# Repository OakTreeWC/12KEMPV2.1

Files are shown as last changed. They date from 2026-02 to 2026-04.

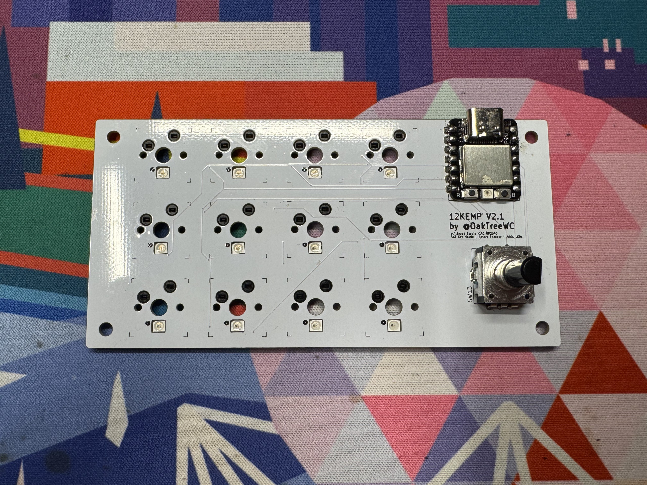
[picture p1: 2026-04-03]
Photos/IMG_2423.jpg

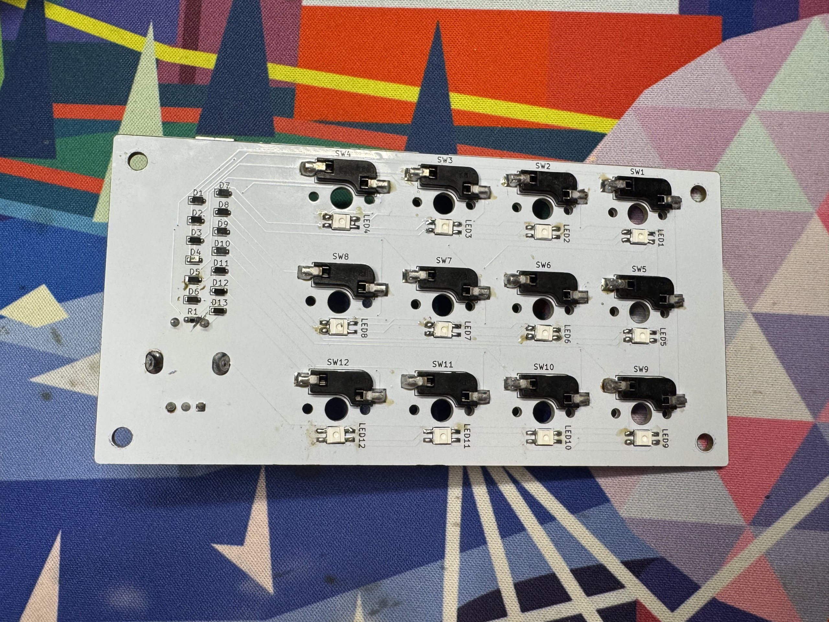
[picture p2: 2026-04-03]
Photos/IMG_2424.jpg

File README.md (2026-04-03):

# 12KEMP V2.1  (Complete)
12KEMP V2.1 is a 12 key 4 by 3 macropad, that features a Xiao SEEED Studio RP2040 with vial-qmk support, a clickable rotary encoder, a completely custom pcb with hot-swap support for 3/5-pin regular MX switches, as well as a complete case. All related files are in this repo, and you may create any form of case to mount the pcb onto, though it may take some time. Additionally, a bill of materials (BOM) is included. 

I made this project, 1. for school, and 2. for the [hackclub blueprint](https://blueprint.hackclub.com) event.

12kemp

## Installing the Firmware
In order to install the firmware on the SEEED Studio RP2040 (RP2350 is not supported in QMK yet), hold the boot button on the microcontroller while plugging it into your computer. Once plugged in, a USB Mass Storage Device should appear. Download and move the .uf2 [firmware file](https://github.com/OakTreeWC/12KEMPV2.1/raw/refs/heads/main/Production/firmware.uf2) to the device. After the firmware has been put on the flash, the microcontroller should restart automatically. The firmware has now been installed.

## Usage
In order to use this project, one can either download Vial from [get.vial.today](https://get.vial.today), or use their [web interface](https://vial.rocks/). When plugged in, the device should show up on the top in a little dropdown. (Web users may have to manually select the device when setting up) If necessary, select the device from the dropdown. Now you can manually change what each key on the macropad does, simply by clicking the key you want to change and selecting what you want it to do from the bottom. You can change what keys on the other layers do as well, by just clicking the numbers right under the dropdown on the left.






## Bill of Materials
|Item |Description |Qty.|Unit Price (USD)|Total Price  (USD)|URL |Running Total (USD + Tax)|
|---|---|----|---|---|---|---|
|XIAO RP2040 |ARM® Cortex®-M0+ MCU 32-Bit Embedded Evaluation Board |1 |$4.68 |$4.68 |https://www.digikey.com/en/products/detail/seeed-technology-co-ltd/102010428/14672129 |$5.16 |
|Rotary Encoder |Rotary Encoder Incremental 24 Quadrature (Incremental) Horizontal |1 |$1.72 |$1.72 |https://www.digikey.com/en/products/detail/bourns-inc/PEC12R-4020F-S0024/4699271 |$7.06 |
|Reverse Neopixels |Addressable Lighting - 10 LED Discrete Red, Green, Blue (RGB) |2 |$2.95 |$5.90 |https://www.digikey.com/en/products/detail/adafruit-industries-llc/4960/14302512 |$13.56 |
|Akko Keyboard Switches|Akko V3 Creamy Yellow Pro Keyboard Switch, 5-Pin 50gf Linear Switches (45pcs) |1 |$12.99 |$12.99 |https://www.amazon.com/Akko-Keyboard-Dustproof-Mechanical-Switches/dp/B0C3H8NVJV |$27.88 |
|Schottky Diodes |Diode 30 V 200mA Surface Mount 0603 |12  |$0.10 |$1.18 |https://www.digikey.com/en/products/detail/taiwan-semiconductor-corporation/TSS54U-RGG/7360711 |$29.18 |
|Resistor |For Neopixel Data Line. 379 Ohms ±0.1% 0.1W, 1/10W Chip Resistor 0603 (1608 Metric)|1 |$0.12 |$0.12 |https://www.digikey.com/en/products/detail/koa-speer-electronics-inc/RN73R1JTTD3790B25/10016392 |$29.31 |
|PCB |PCB Manufactured by JLCPCB. White, 1.6mm, HASL w/ lead |5 |$1.32 |$6.60 |https://jlcpcb.com |$36.59 |
|Lower Case |Case Manufactured by JLC3DP. Black Resin |1 |$12.47 |$12.47 |https://jlc3dp.com |$50.34 |
|Upper Case |Case Manufactured by JLCPCB. Grey Resin |1 |$2.51 |$2.51 |https://jlc3dp.com |$53.11 |
|Keycaps |DSA Keycaps White 24pcs |1 |$8.99 |$8.99 |www.amazon.com/Mechkeeb-Profile-Switches-Keyboard-Replacement/dp/B0BWDTBF1L |$63.02 |
|Rotary Encoder Knob |Aluminum Rotary Encoder Knob 2pcs |1 |$8.99 |$8.99 |www.amazon.com/Szliyands-Aluminum-Electronic-Potentiometer-Knob，Switch/dp/B099PX52LW |$72.93 |
|Threaded Inserts |M3 Threaded Inserts 152pcs |1 |$6.99 |$6.99 |https://www.amazon.com/Vibit-Threaded-Soldering-Printing-Components/dp/B0FWWW8VP1/ref=sr_1_3 |$80.64 |
|Machine Screws |M3 Screw Kit |1 |$9.99 |$9.99 |https://www.amazon.com/Fgruh-750PCS-Assortment-Washers-Assorted/dp/B0FGV5FCBN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|$91.65 |
|Digikey Shipping | |1 |$4.99 |$4.99 | |$97.15 |
|JLC Shipping | |1 |$10.73 |$10.73 | |$108.98 |

## Licensing

Copyright 2026 William C.

Licensed under the Apache License, Version 2.0 (the "License");
you may not use this file except in compliance with the License.
You may obtain a copy of the License at

http://www.apache.org/licenses/LICENSE-2.0

Unless required by applicable law or agreed to in writing, software
distributed under the License is distributed on an "AS IS" BASIS,
WITHOUT WARRANTIES OR CONDITIONS OF ANY KIND, either express or implied.
See the License for the specific language governing permissions and
limitations under the License.

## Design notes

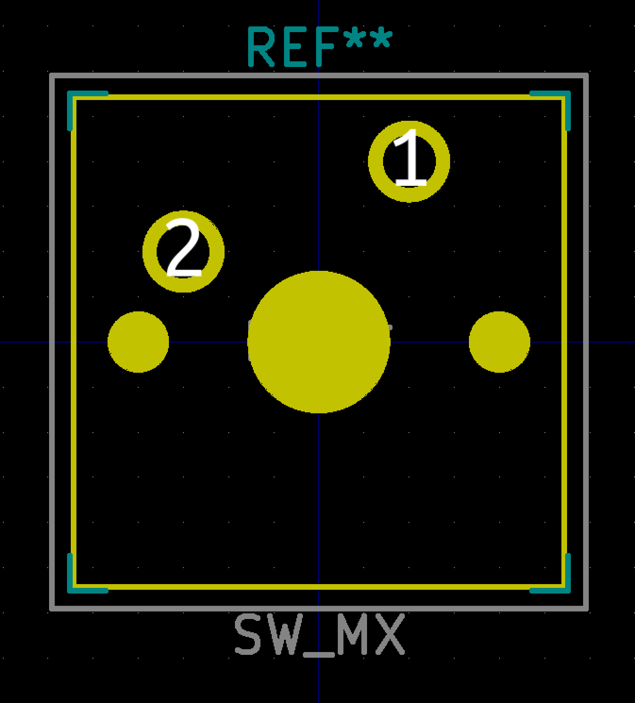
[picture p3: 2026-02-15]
KiCad Files/cad files/keyswitches.pretty-2.1/images/SW_MX.png

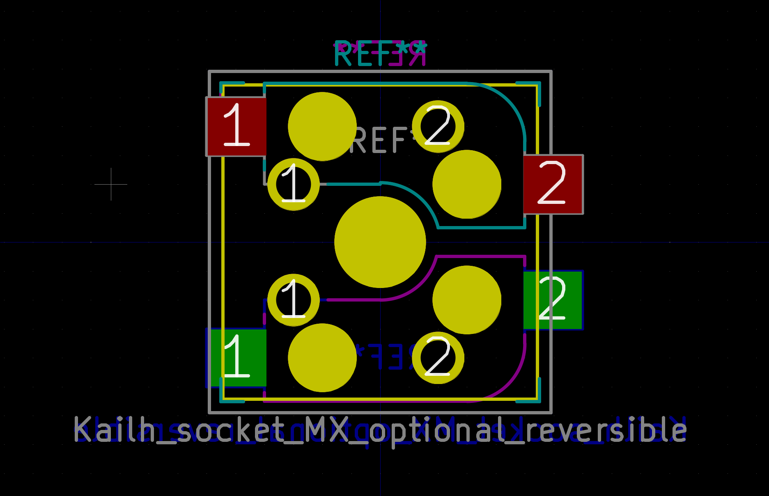
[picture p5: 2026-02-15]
KiCad Files/cad files/keyswitches.pretty-2.1/images/Kailh_socket_MX_optional_reversible_platemount.png

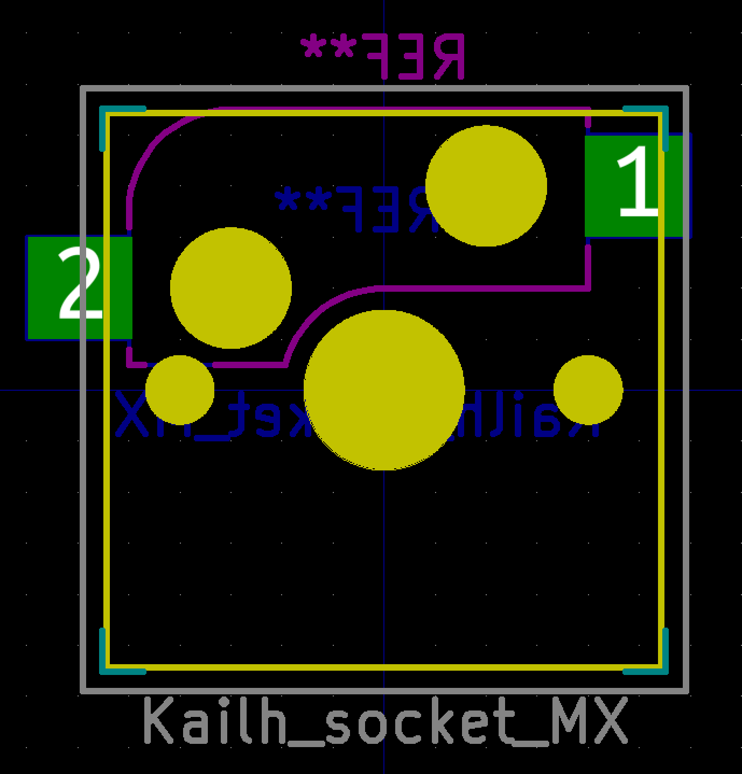
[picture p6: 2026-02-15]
KiCad Files/cad files/keyswitches.pretty-2.1/images/Kailh_socket_MX.png

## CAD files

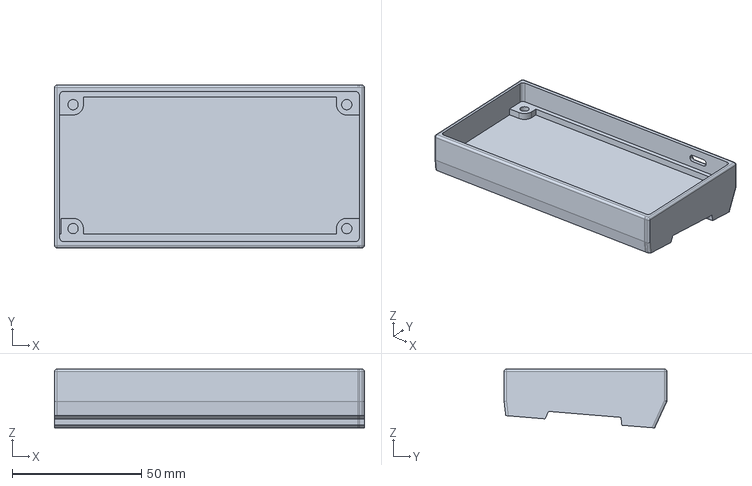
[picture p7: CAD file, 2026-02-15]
CAD/Case/12KEMP V2.1 LowerCase.step
120.1 x 63.1 x 22.8 mm

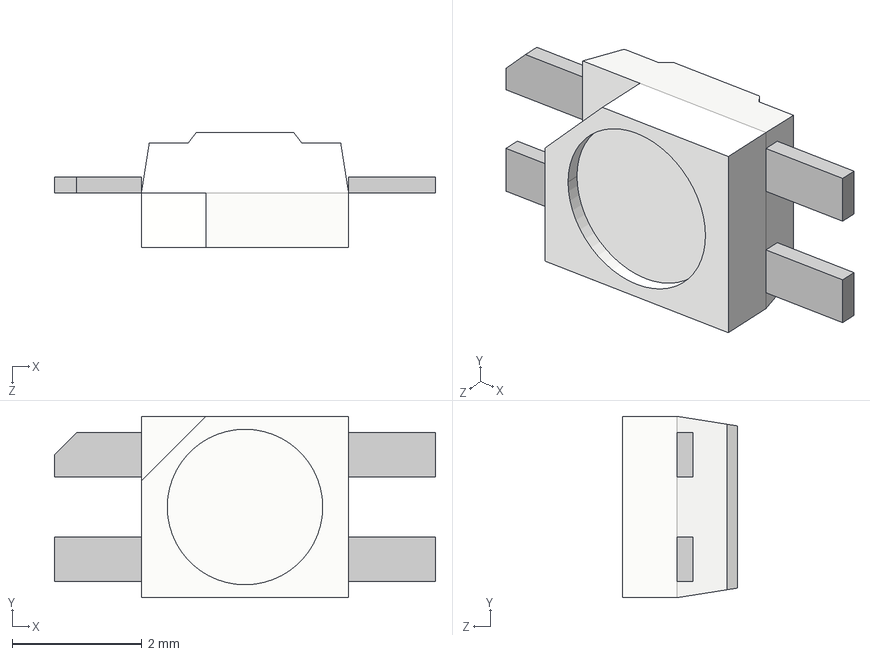
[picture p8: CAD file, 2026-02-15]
KiCad Files/cad files/4960/KiCADv6/4960.stp
5.88 x 2.80 x 1.78 mm

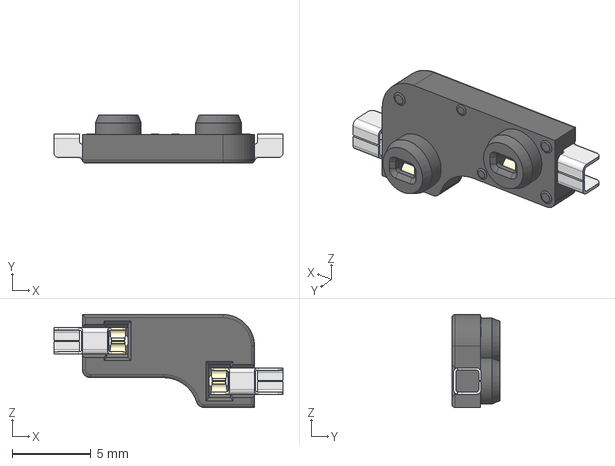
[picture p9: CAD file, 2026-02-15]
KiCad Files/cad files/MX-Hotswap-Socket.step
14.5 x 3.05 x 5.89 mm

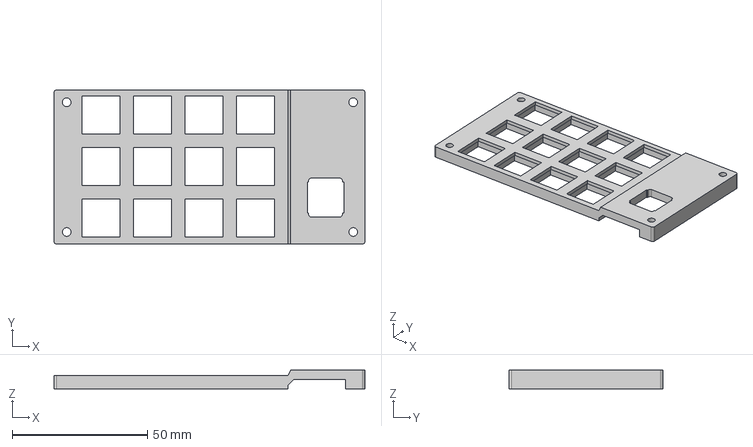
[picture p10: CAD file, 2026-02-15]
CAD/Case/12KEMP V2.1 UpperCase.step
115.1 x 57.1 x 6.90 mm

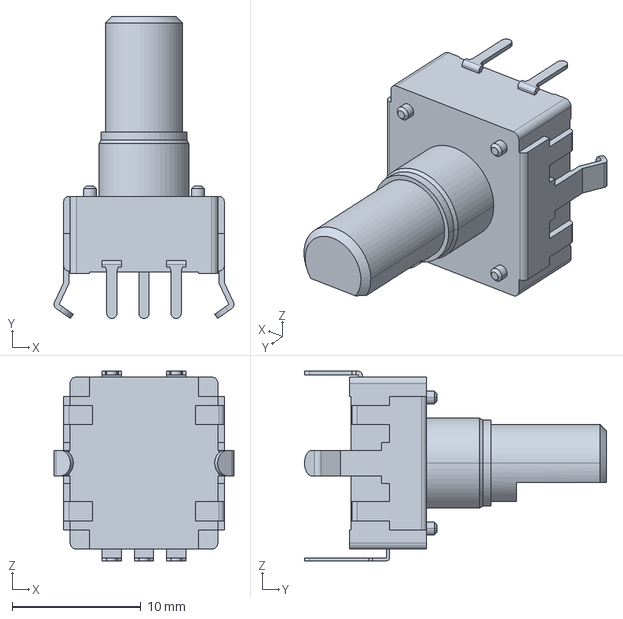
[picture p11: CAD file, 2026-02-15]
KiCad Files/cad files/pec12r-4x20f-sxxxx.step
14.0 x 23.5 x 14.7 mm

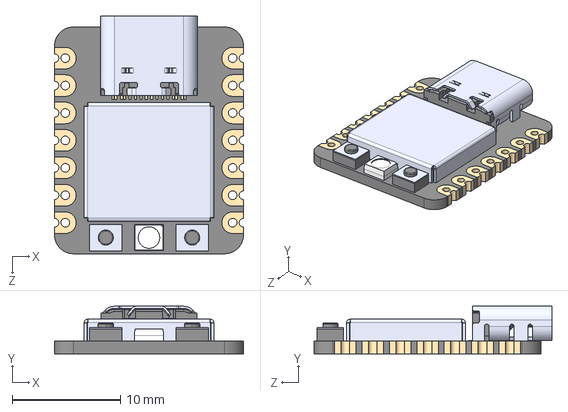
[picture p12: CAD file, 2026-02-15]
KiCad Files/cad files/102010428.step
17.5 x 4.40 x 22.0 mm

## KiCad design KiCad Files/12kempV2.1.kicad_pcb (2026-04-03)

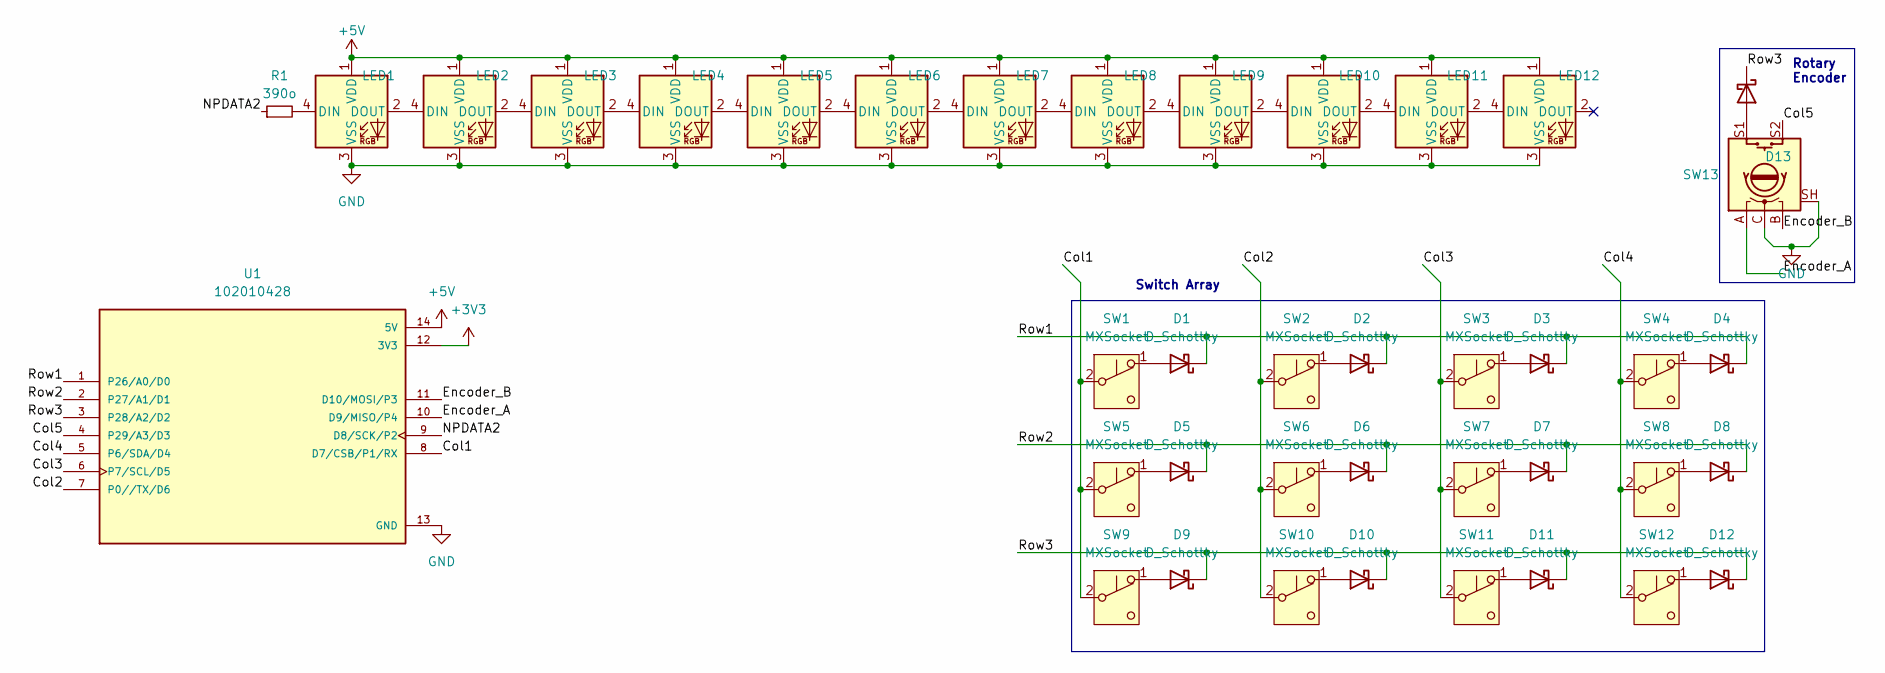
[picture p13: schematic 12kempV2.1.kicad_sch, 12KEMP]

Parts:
D1, D2, D3, D4, D5, D6, D7, D8, D9, D10, D11, D12, D13: D_Schottky; D_0603_1608Metric_Pad1.05x0.95mm_HandSolder
LED1, LED2, LED3, LED4, LED5, LED6, LED7, LED8, LED9, LED10, LED11, LED12: NeoPixel_THT; 4960_ADA
R1: 390o; R_0603_1608Metric_Pad0.98x0.95mm_HandSolder
SW1, SW2, SW3, SW4, SW5, SW6, SW7, SW8, SW9, SW10, SW11, SW12: MXSocket; Kailh_socket_MX
SW13: RotaryEncoder_Switch; RotaryEncoder_Bourns_Vertical_PEC12R-3x17F-Sxxxx
U1: 102010428; MODULE_102010428; PARTREV 1.3

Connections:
+3V3: U1.12 (3V3)
+5V: LED1.1 (VDD), LED2.1 (VDD), LED3.1 (VDD), LED4.1 (VDD), LED5.1 (VDD), LED6.1 (VDD), LED7.1 (VDD), LED8.1 (VDD), LED9.1 (VDD), LED10.1 (VDD), LED11.1 (VDD), LED12.1 (VDD), U1.14 (5V)
/Col1: SW1.2 (B), SW5.2 (B), SW9.2 (B), U1.8 (D7/CSB/P1/RX)
/Col2: SW2.2 (B), SW6.2 (B), SW10.2 (B), U1.7 (P0//TX/D6)
/Col3: SW3.2 (B), SW7.2 (B), SW11.2 (B), U1.6 (P7/SCL/D5)
/Col4: SW4.2 (B), SW8.2 (B), SW12.2 (B), U1.5 (P6/SDA/D4)
/Col5: SW13.S2, U1.4 (P29/A3/D3)
/Encoder_A: SW13.A, U1.10 (D9/MISO/P4)
/Encoder_B: SW13.B, U1.11 (D10/MOSI/P3)
/NPDATA2: R1.1, U1.9 (D8/SCK/P2)
/Row1: D1.1 (K), D2.1 (K), D3.1 (K), D4.1 (K), U1.1 (P26/A0/D0)
/Row2: D5.1 (K), D6.1 (K), D7.1 (K), D8.1 (K), U1.2 (P27/A1/D1)
/Row3: D9.1 (K), D10.1 (K), D11.1 (K), D12.1 (K), D13.1 (K), U1.3 (P28/A2/D2)
GND: LED1.3 (VSS), LED2.3 (VSS), LED3.3 (VSS), LED4.3 (VSS), LED5.3 (VSS), LED6.3 (VSS), LED7.3 (VSS), LED8.3 (VSS), LED9.3 (VSS), LED10.3 (VSS), LED11.3 (VSS), LED12.3 (VSS), SW13.C, SW13.SH (SHIELD), U1.13 (GND)
unnamed: D1.2 (A), SW1.1 (A)
unnamed: D2.2 (A), SW2.1 (A)
unnamed: D3.2 (A), SW3.1 (A)
unnamed: D4.2 (A), SW4.1 (A)
unnamed: D5.2 (A), SW5.1 (A)
unnamed: D6.2 (A), SW6.1 (A)
unnamed: D7.2 (A), SW7.1 (A)
unnamed: D8.2 (A), SW8.1 (A)
unnamed: D9.2 (A), SW9.1 (A)
unnamed: D10.2 (A), SW10.1 (A)
unnamed: D11.2 (A), SW11.1 (A)
unnamed: D12.2 (A), SW12.1 (A)
unnamed: D13.2 (A), SW13.S1
unnamed: LED1.4 (DIN), R1.2
unnamed: LED1.2 (DOUT), LED2.4 (DIN)
unnamed: LED2.2 (DOUT), LED3.4 (DIN)
unnamed: LED3.2 (DOUT), LED4.4 (DIN)
unnamed: LED4.2 (DOUT), LED5.4 (DIN)
unnamed: LED5.2 (DOUT), LED6.4 (DIN)
unnamed: LED6.2 (DOUT), LED7.4 (DIN)
unnamed: LED7.2 (DOUT), LED8.4 (DIN)
unnamed: LED8.2 (DOUT), LED9.4 (DIN)
unnamed: LED9.2 (DOUT), LED10.4 (DIN)
unnamed: LED10.2 (DOUT), LED11.4 (DIN)
unnamed: LED11.2 (DOUT), LED12.4 (DIN)

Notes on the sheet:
Rotary Encoder
Switch Array

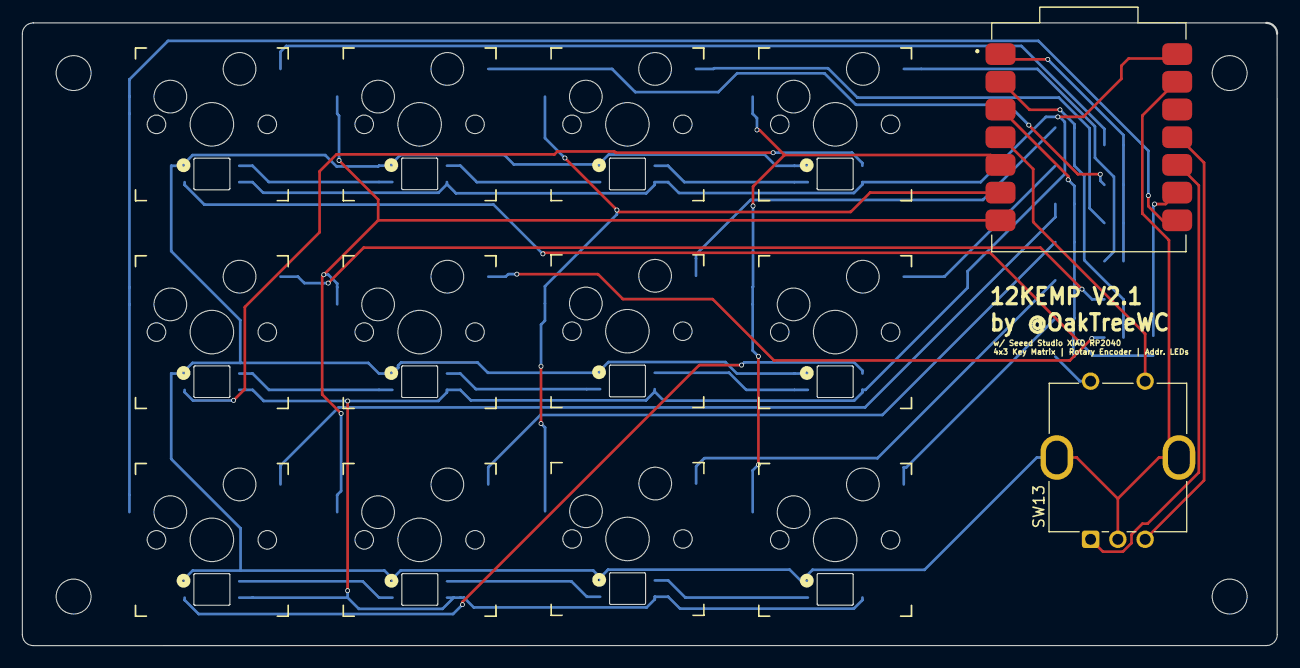
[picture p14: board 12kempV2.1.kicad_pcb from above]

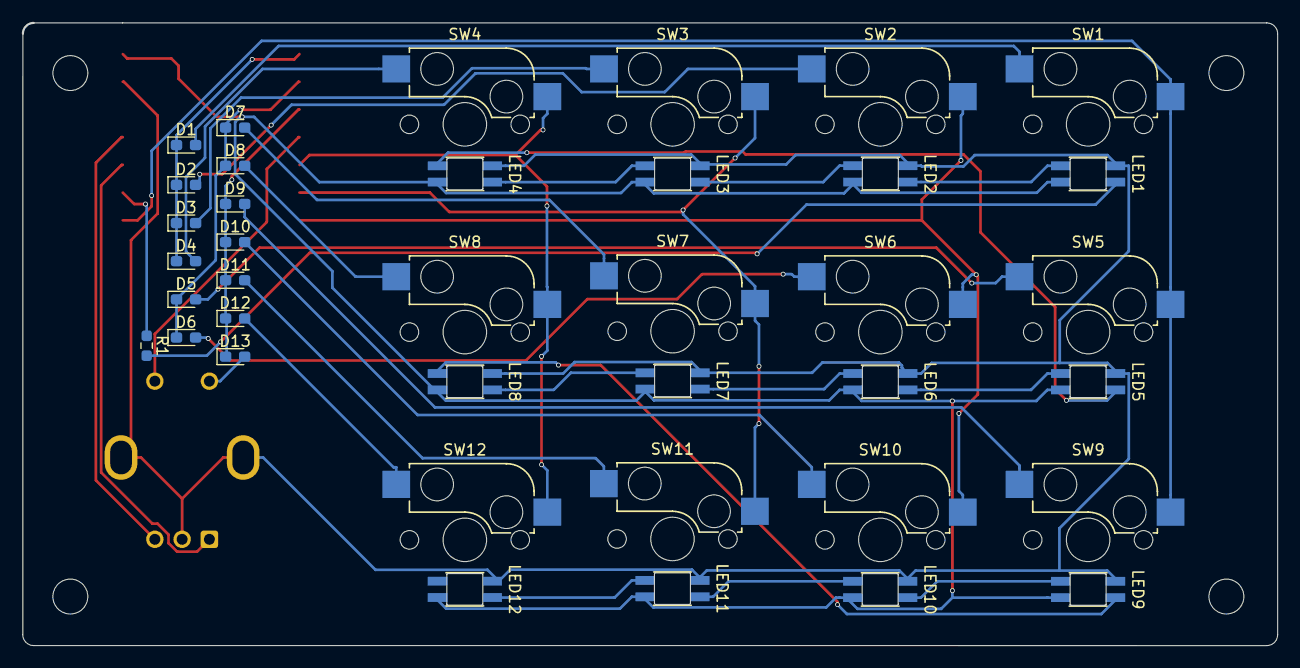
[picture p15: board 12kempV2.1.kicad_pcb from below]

Board: 2 copper layers, 115.1 x 57.1 mm, 40 parts (26 on the bottom side), 38 nets.

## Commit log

2026-02-15 Init Commit
    [102010428.step, 12KEMP V2.1 LowerCase.step, 12KEMP V2.1 UpperCase.step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]
2026-02-15 Added BOM
    [12KEMP V2.1 BOM.csv]
2026-02-15 Revise README with new hardware details and BOM
    Updated project description and added Bill of Materials.
2026-02-15 Fix shipping cost entries in BOM
    Updated shipping costs for Digikey and JLC.
    [12KEMP V2.1 BOM.csv]
2026-02-15 Fixed a typo in the BOM
    [12KEMP V2.1 BOM.csv]
2026-02-20 Organized the kicad files and fixed an error in the PCB
    [102010428.step, 12kempV2.1.kicad_pcb, 12kempV2.1.kicad_sch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]
2026-02-20 Added another folder to the commit
    [102010428.step, 12kempV2.1.kicad_pcb, 12kempV2.1.kicad_sch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]
2026-02-23 Added schematic pic
